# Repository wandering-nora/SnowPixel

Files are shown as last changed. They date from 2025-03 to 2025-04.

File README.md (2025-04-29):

# SnowPixel
Yet another 8x8 neopixel matrix... But hear me out, this one is a little special ❄️ 

This is a small 20x20x1.3mm module that can be seamlessly tiled without any wiring by soldering them together with the castellated holes.  
The built in solder jumpers in the data pads let the user decide whether the module sends and receives the data straight accross or at a 90 degree angle making any configuration possible.

The modules are meant to be used standalone or as an smd component in and of itself.  
The leds used are XL-1010RGBC-WS2812B 1x1mm leds which are the smallest currently available.  
If you have a clean 5V supply the capacitors on the back are usually not needed.  
This project is meant mainly as a test to push the pcb fab's specs to the limit and try a couple 3D printing ideas to obtain a thin, seamless display.



## 3D print
The 3D printed case is what brings the SnowPixel to life giving it proper square pixels. There's a standalone version for generic use and an smd version for when the pcb is soldered directly on a bigger pcb.  

The STL folder contains a bunch of common configurations, but the models are fully modular and can be easily edited with the OpenSCAD files.  

I'm currently experimenting with two methods for diffusing the light.  

### PET
These models are meant to be printed with PET (not PETG) on a PET diffusion film substrate.
This can be done by modifying a little the G-code to add an offset equal to the thickness of the film.

### PLA
These models are much simpler to print, they can be printed with normal pla (or any other plastic really) and only need the first layer to be printed in white and the rest in black.

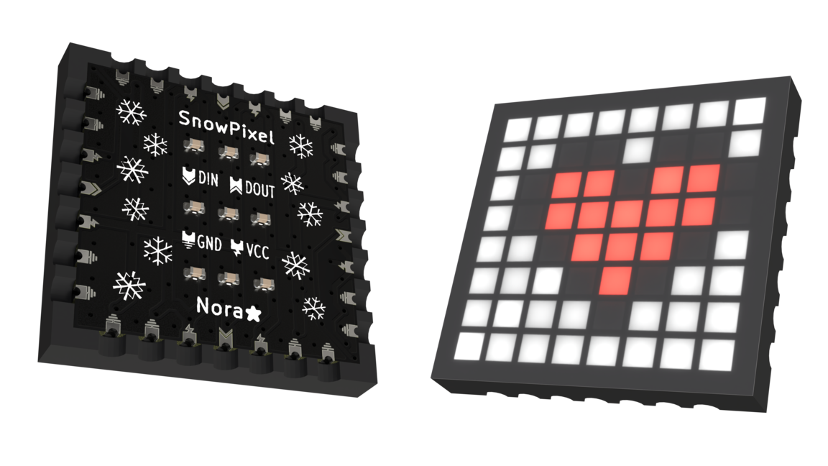
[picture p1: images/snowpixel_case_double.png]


 > Not an amazing render, I will update it with proper photos soon

## Manufacturing update
Even if quite out of spec for JLCPCB's cheapest offering (not paying for castellated holes and definitely going over spec for both the copper and silkscreen layers) the boards all turned out mostly fine!  
They definitely needed some cleanup as the edges were filled with burs from the castellated holes and the LED silkscreen wasn't printed all the way around.  
The boards are otherwise perfectly functional and pretty simple to assemble by hand with an hotplate.

#### Todo for v1.2
- [ ] Modify data jumpers for easier operation. (Maybe cuttable traces?)
- [ ] Make leds silkscreen thicker.

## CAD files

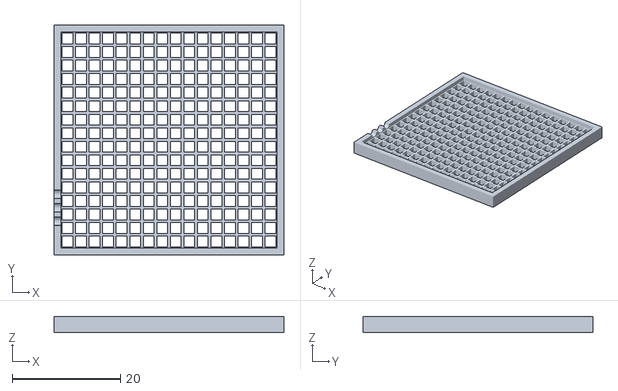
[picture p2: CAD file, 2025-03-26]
case/STL/PET/snowpixel_pet_16x16.stl
42.5 x 42.5 x 3.00

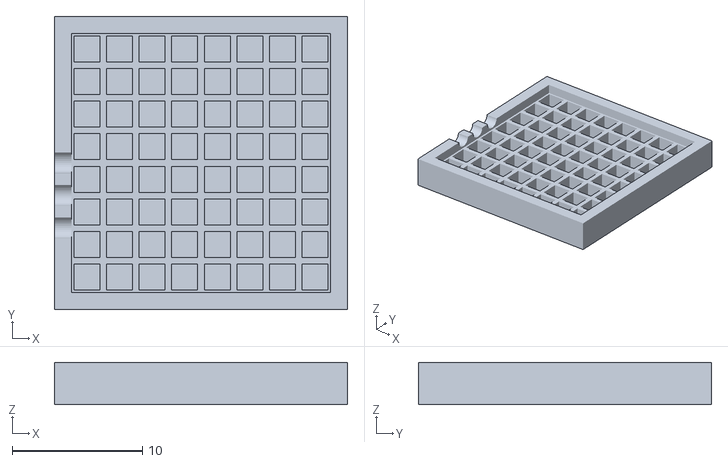
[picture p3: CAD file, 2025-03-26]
case/STL/PLA/snowpixel_pla_8x8.stl
22.5 x 22.5 x 3.25

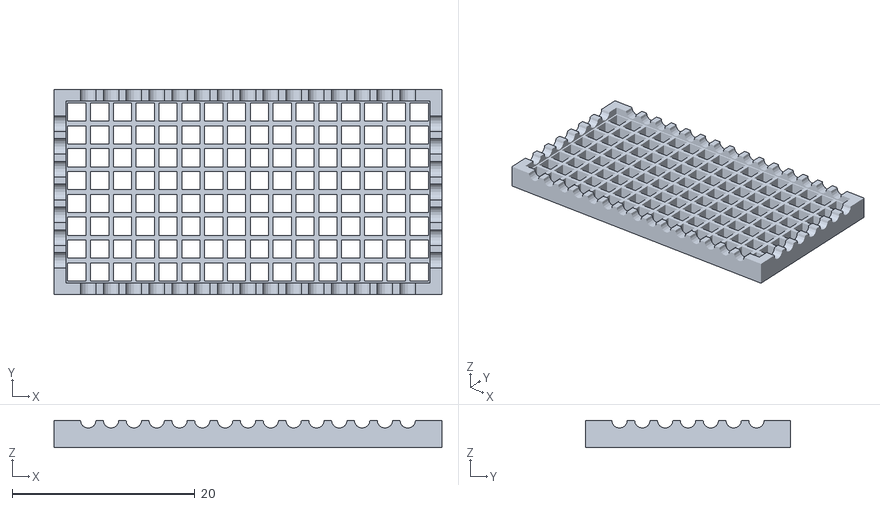
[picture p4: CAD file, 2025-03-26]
case/STL/PET/snowpixel_smd_pet_8x16.stl
42.5 x 22.5 x 3.00

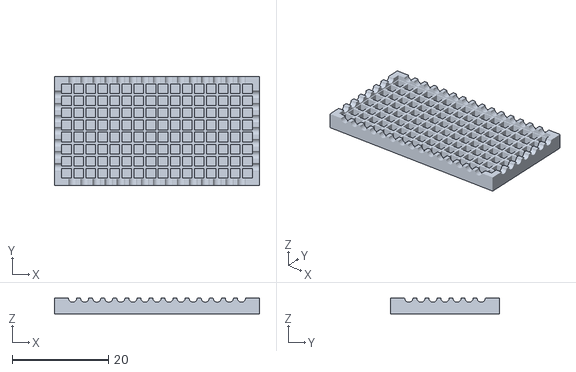
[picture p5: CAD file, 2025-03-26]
case/STL/PLA/snowpixel_smd_pla_8x16.stl
42.5 x 22.5 x 3.25

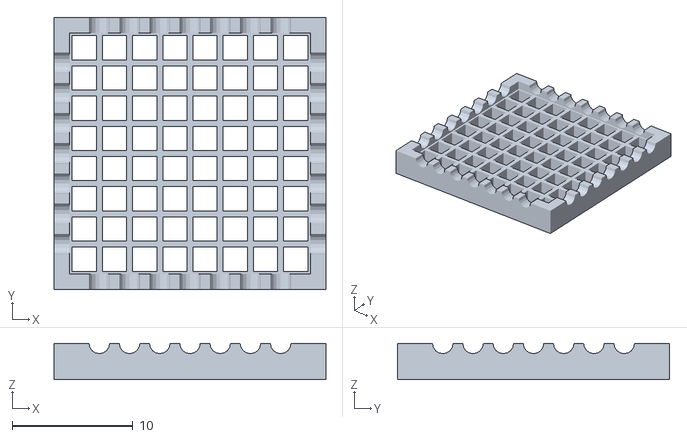
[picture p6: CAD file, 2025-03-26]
case/STL/PET/snowpixel_smd_pet_8x8.stl
22.5 x 22.5 x 3.00

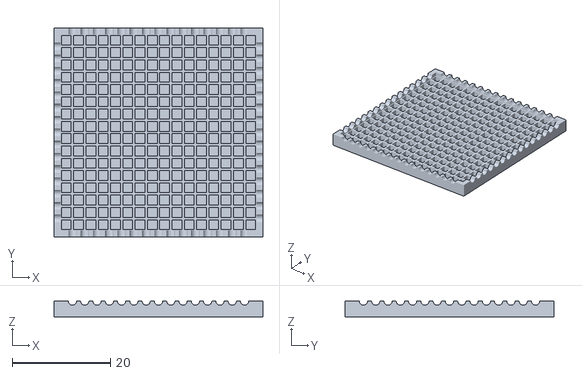
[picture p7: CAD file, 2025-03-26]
case/STL/PLA/snowpixel_smd_pla_16x16.stl
42.5 x 42.5 x 3.25

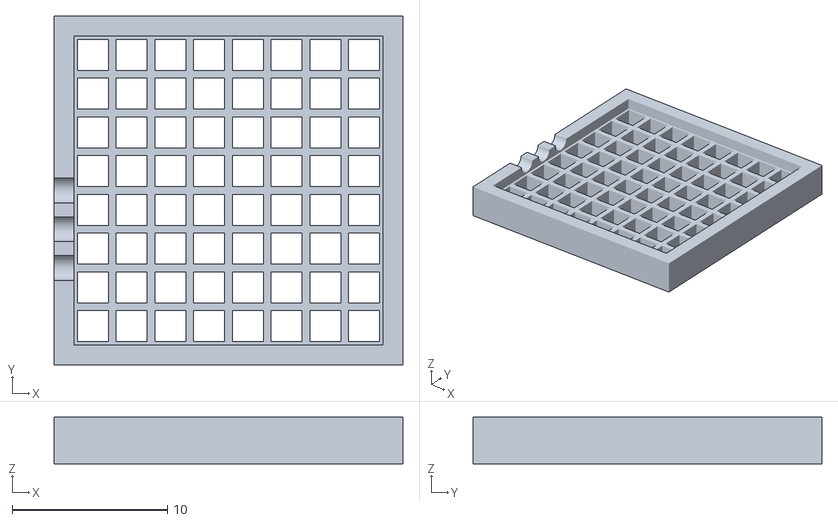
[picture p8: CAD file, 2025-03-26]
case/STL/PET/snowpixel_pet_8x8.stl
22.5 x 22.5 x 3.00

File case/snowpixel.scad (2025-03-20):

grid_size_x = 16; // number of pixels on x
grid_size_y = 16; // number of pixels on y

cell_size = 2.5; // pitch between pixels
inner_wall_thickness = 0.5; // I think you get this one
outer_wall_thickness = 1.5; // this one too
inner_wall_height = 2; // minimum TBD by experimentation
outer_wall_height = inner_wall_height + 1;
pcb_tolerance = 0.2; //wiggle room for pcb

hole_size = 0.5; // size for cable holes  

module grid() { // make readable code they said... 
    translate([0, 0, 0])
            cube([grid_size_y * cell_size - inner_wall_thickness + 2 * outer_wall_thickness, outer_wall_thickness, inner_wall_height]);
    translate([0, 0, inner_wall_height])
            cube([grid_size_y * cell_size - inner_wall_thickness + 2 * outer_wall_thickness, outer_wall_thickness - pcb_tolerance, outer_wall_height - inner_wall_height]);
    
    for (y = [1 : 1 : grid_size_x -1]) {
        translate([outer_wall_thickness, y * cell_size + outer_wall_thickness - inner_wall_thickness, 0])
            cube([grid_size_y * cell_size - inner_wall_thickness, inner_wall_thickness, inner_wall_height]);
    }
    
    translate([0, grid_size_x * cell_size + outer_wall_thickness - inner_wall_thickness, 0])
            cube([grid_size_y * cell_size - inner_wall_thickness + 2 * outer_wall_thickness, outer_wall_thickness, inner_wall_height]);
    translate([0, grid_size_x * cell_size + outer_wall_thickness - inner_wall_thickness + pcb_tolerance, inner_wall_height])
           cube([grid_size_y * cell_size - inner_wall_thickness + 2 * outer_wall_thickness, outer_wall_thickness - pcb_tolerance, outer_wall_height - inner_wall_height]);
    
    
    translate([0, 0, 0])
            cube([outer_wall_thickness, grid_size_x * cell_size - inner_wall_thickness + 2 * outer_wall_thickness, inner_wall_height]); 
    translate([0, 0, inner_wall_height])
            cube([outer_wall_thickness - pcb_tolerance, grid_size_x * cell_size - inner_wall_thickness + 2 * outer_wall_thickness, outer_wall_height - inner_wall_height]);
    
    for (x = [1 : 1 : grid_size_y - 1]) {
        translate([x * cell_size + outer_wall_thickness -inner_wall_thickness, outer_wall_thickness, 0])
            cube([inner_wall_thickness, grid_size_x * cell_size - inner_wall_thickness, inner_wall_height]);
    }
    
    translate([grid_size_y * cell_size + outer_wall_thickness - inner_wall_thickness, 0, 0])
            cube([outer_wall_thickness, grid_size_x * cell_size - inner_wall_thickness + 2 * outer_wall_thickness, inner_wall_height]);
    translate([grid_size_y * cell_size + outer_wall_thickness - inner_wall_thickness + pcb_tolerance, 0, inner_wall_height])
            cube([outer_wall_thickness - pcb_tolerance, grid_size_x * cell_size - inner_wall_thickness + 2 * outer_wall_thickness, outer_wall_height - inner_wall_height]);
}


color([0.9,0.8,1]) difference() { // make hole for cables 
    grid();
    translate([-0.1, cell_size * 2 - inner_wall_thickness/2 + outer_wall_thickness, outer_wall_height])
    rotate([0,90,0])
    cylinder(r=hole_size, h=outer_wall_height + 1, $fn=100);
    translate([-0.1, cell_size * 3 - inner_wall_thickness/2 + outer_wall_thickness, outer_wall_height])
    rotate([0,90,0])
    cylinder(r=hole_size, h=outer_wall_height + 1, $fn=100);
    translate([-0.1, cell_size * 4 - inner_wall_thickness/2 + outer_wall_thickness, outer_wall_height])
    rotate([0,90,0])
    cylinder(r=hole_size, h=outer_wall_height + 1, $fn=100);
    }

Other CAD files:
case/STL/PLA/snowpixel_pla_8x16.stl
case/STL/PET/snowpixel_pet_8x16.stl
case/STL/PLA/snowpixel_smd_pla_8x8.stl
case/STL/PET/snowpixel_smd_pet_16x16.stl
case/STL/PLA/snowpixel_pla_16x16.stl
case/snowpixel_pet.scad
case/snowpixel_pla.scad
case/snowpixel_smd.scad
case/OpenSCAD/snowpixel_pet.scad
case/OpenSCAD/snowpixel_pla.scad
case/OpenSCAD/snowpixel_smd_pet.scad
case/OpenSCAD/snowpixel_smd_pla.scad
case/snowpixel_smd_pla.scad

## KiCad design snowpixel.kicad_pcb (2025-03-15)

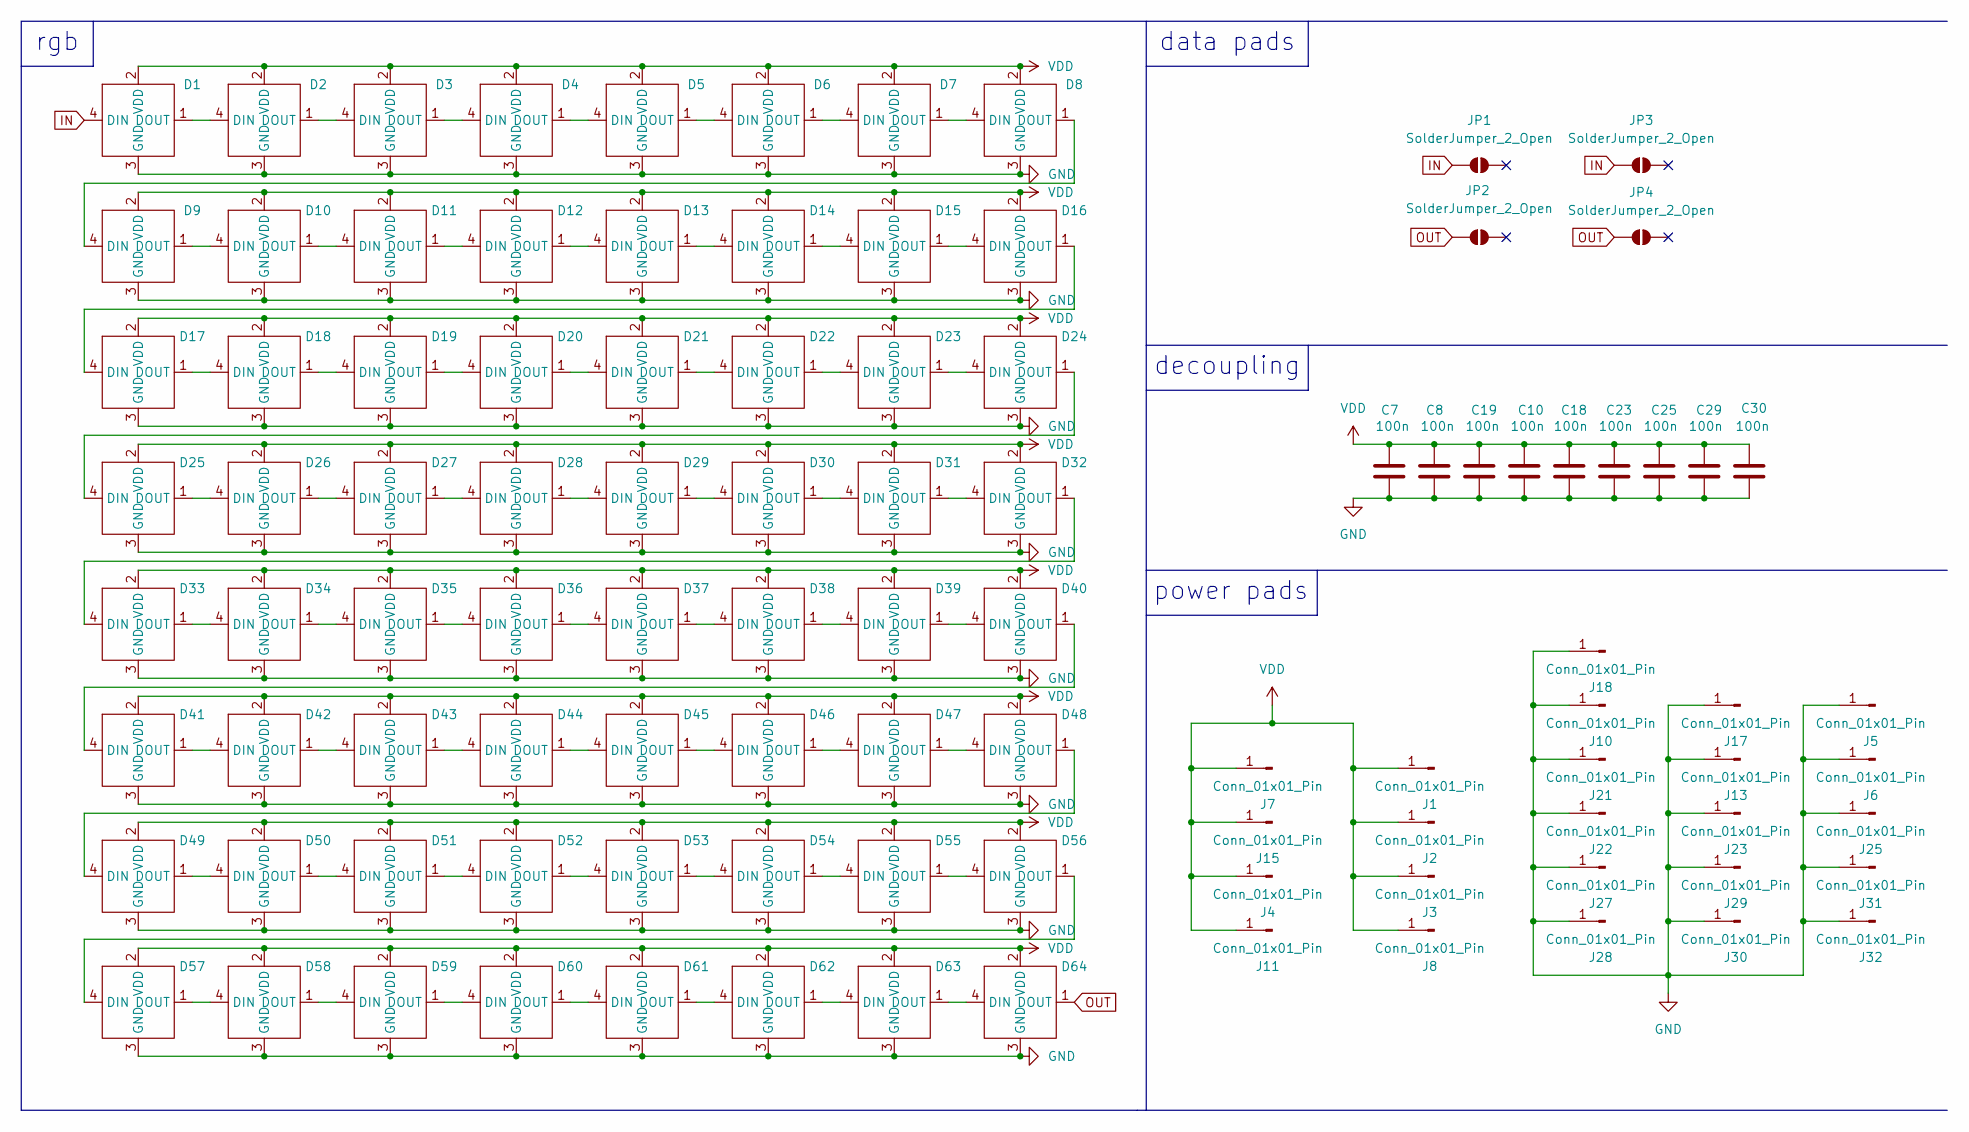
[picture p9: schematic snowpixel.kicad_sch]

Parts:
C7, C8, C10, C18, C19, C23, C25, C29, C30: 100n; C_0402_1005Metric
D1, D2, D3, D4, D5, D6, D7, D8, D9, D10, D11, D12, D13, D14, D15, D16, D17, D18, D19, D20, D21, D22, D23, D24, D25, D26, D27, D28, D29, D30, D31, D32, D33, D34, D35, D36, D37, D38, D39, D40, D41, D42, D43, D44, D45, D46, D47, D48, D49, D50, D51, D52, D53, D54, D55, D56, D57, D58, D59, D60, D61, D62, D63, D64: XL-1010RGBC-WS28128B
J1, J2, J3, J4, J7, J8, J11, J15: Conn_01x01_Pin; matrix-pad-vcc
J5, J6, J10, J13, J17, J18, J21, J22, J23, J25, J27, J28, J29, J30, J31, J32: Conn_01x01_Pin; matrix-pad-gn
JP1, JP3: SolderJumper_2_Open; matrix-pad-din
JP2, JP4: SolderJumper_2_Open; matrix-pad-dout

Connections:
GND: C7.2, C8.2, C10.2, C18.2, C19.2, C23.2, C25.2, C29.2, C30.2, D1.3 (GND), D2.3 (GND), D3.3 (GND), D4.3 (GND), D5.3 (GND), D6.3 (GND), D7.3 (GND), D8.3 (GND), D9.3 (GND), D10.3 (GND), D11.3 (GND), D12.3 (GND), D13.3 (GND), D14.3 (GND), D15.3 (GND), D16.3 (GND), D17.3 (GND), D18.3 (GND), D19.3 (GND), D20.3 (GND), D21.3 (GND), D22.3 (GND), D23.3 (GND), D24.3 (GND), D25.3 (GND), D26.3 (GND), D27.3 (GND), D28.3 (GND), D29.3 (GND), D30.3 (GND), D31.3 (GND), D32.3 (GND), D33.3 (GND), D34.3 (GND), D35.3 (GND), D36.3 (GND), D37.3 (GND), D38.3 (GND), D39.3 (GND), D40.3 (GND), D41.3 (GND), D42.3 (GND), D43.3 (GND), D44.3 (GND), D45.3 (GND), D46.3 (GND), D47.3 (GND), D48.3 (GND), D49.3 (GND), D50.3 (GND), D51.3 (GND), D52.3 (GND), D53.3 (GND), D54.3 (GND), D55.3 (GND), D56.3 (GND), D57.3 (GND), D58.3 (GND), D59.3 (GND), D60.3 (GND), D61.3 (GND), D62.3 (GND), D63.3 (GND), D64.3 (GND), J5.1, J6.1, J10.1, J13.1, J17.1, J18.1, J21.1, J22.1, J23.1, J25.1, J27.1, J28.1, J29.1, J30.1, J31.1, J32.1
IN: D1.4 (DIN), JP1.2 (B), JP3.2 (B)
unnamed: D1.1 (DOUT), D2.4 (DIN)
unnamed: D2.1 (DOUT), D3.4 (DIN)
unnamed: D3.1 (DOUT), D4.4 (DIN)
unnamed: D4.1 (DOUT), D5.4 (DIN)
unnamed: D5.1 (DOUT), D6.4 (DIN)
unnamed: D6.1 (DOUT), D7.4 (DIN)
unnamed: D7.1 (DOUT), D8.4 (DIN)
unnamed: D8.1 (DOUT), D9.4 (DIN)
unnamed: D9.1 (DOUT), D10.4 (DIN)
unnamed: D10.1 (DOUT), D11.4 (DIN)
unnamed: D11.1 (DOUT), D12.4 (DIN)
unnamed: D12.1 (DOUT), D13.4 (DIN)
unnamed: D13.1 (DOUT), D14.4 (DIN)
unnamed: D14.1 (DOUT), D15.4 (DIN)
unnamed: D15.1 (DOUT), D16.4 (DIN)
unnamed: D16.1 (DOUT), D17.4 (DIN)
unnamed: D17.1 (DOUT), D18.4 (DIN)
unnamed: D18.1 (DOUT), D19.4 (DIN)
unnamed: D19.1 (DOUT), D20.4 (DIN)
unnamed: D20.1 (DOUT), D21.4 (DIN)
unnamed: D21.1 (DOUT), D22.4 (DIN)
unnamed: D22.1 (DOUT), D23.4 (DIN)
unnamed: D23.1 (DOUT), D24.4 (DIN)
unnamed: D24.1 (DOUT), D25.4 (DIN)
unnamed: D25.1 (DOUT), D26.4 (DIN)
unnamed: D26.1 (DOUT), D27.4 (DIN)
unnamed: D27.1 (DOUT), D28.4 (DIN)
unnamed: D28.1 (DOUT), D29.4 (DIN)
unnamed: D29.1 (DOUT), D30.4 (DIN)
unnamed: D30.1 (DOUT), D31.4 (DIN)
unnamed: D31.1 (DOUT), D32.4 (DIN)
unnamed: D32.1 (DOUT), D33.4 (DIN)
unnamed: D33.1 (DOUT), D34.4 (DIN)
unnamed: D34.1 (DOUT), D35.4 (DIN)
unnamed: D35.1 (DOUT), D36.4 (DIN)
unnamed: D36.1 (DOUT), D37.4 (DIN)
unnamed: D37.1 (DOUT), D38.4 (DIN)
unnamed: D38.1 (DOUT), D39.4 (DIN)
unnamed: D39.1 (DOUT), D40.4 (DIN)
unnamed: D40.1 (DOUT), D41.4 (DIN)
unnamed: D41.1 (DOUT), D42.4 (DIN)
unnamed: D42.1 (DOUT), D43.4 (DIN)
unnamed: D43.1 (DOUT), D44.4 (DIN)
unnamed: D44.1 (DOUT), D45.4 (DIN)
unnamed: D45.1 (DOUT), D46.4 (DIN)
unnamed: D46.1 (DOUT), D47.4 (DIN)
unnamed: D47.1 (DOUT), D48.4 (DIN)
unnamed: D48.1 (DOUT), D49.4 (DIN)
unnamed: D49.1 (DOUT), D50.4 (DIN)
unnamed: D50.1 (DOUT), D51.4 (DIN)
unnamed: D51.1 (DOUT), D52.4 (DIN)
unnamed: D52.1 (DOUT), D53.4 (DIN)
unnamed: D53.1 (DOUT), D54.4 (DIN)
unnamed: D54.1 (DOUT), D55.4 (DIN)
unnamed: D55.1 (DOUT), D56.4 (DIN)
unnamed: D56.1 (DOUT), D57.4 (DIN)
unnamed: D57.1 (DOUT), D58.4 (DIN)
unnamed: D58.1 (DOUT), D59.4 (DIN)
unnamed: D59.1 (DOUT), D60.4 (DIN)
unnamed: D60.1 (DOUT), D61.4 (DIN)
unnamed: D61.1 (DOUT), D62.4 (DIN)
unnamed: D62.1 (DOUT), D63.4 (DIN)
unnamed: D63.1 (DOUT), D64.4 (DIN)
OUT: D64.1 (DOUT), JP2.2 (B), JP4.2 (B)
VDD: C7.1, C8.1, C10.1, C18.1, C19.1, C23.1, C25.1, C29.1, C30.1, D1.2 (VDD), D2.2 (VDD), D3.2 (VDD), D4.2 (VDD), D5.2 (VDD), D6.2 (VDD), D7.2 (VDD), D8.2 (VDD), D9.2 (VDD), D10.2 (VDD), D11.2 (VDD), D12.2 (VDD), D13.2 (VDD), D14.2 (VDD), D15.2 (VDD), D16.2 (VDD), D17.2 (VDD), D18.2 (VDD), D19.2 (VDD), D20.2 (VDD), D21.2 (VDD), D22.2 (VDD), D23.2 (VDD), D24.2 (VDD), D25.2 (VDD), D26.2 (VDD), D27.2 (VDD), D28.2 (VDD), D29.2 (VDD), D30.2 (VDD), D31.2 (VDD), D32.2 (VDD), D33.2 (VDD), D34.2 (VDD), D35.2 (VDD), D36.2 (VDD), D37.2 (VDD), D38.2 (VDD), D39.2 (VDD), D40.2 (VDD), D41.2 (VDD), D42.2 (VDD), D43.2 (VDD), D44.2 (VDD), D45.2 (VDD), D46.2 (VDD), D47.2 (VDD), D48.2 (VDD), D49.2 (VDD), D50.2 (VDD), D51.2 (VDD), D52.2 (VDD), D53.2 (VDD), D54.2 (VDD), D55.2 (VDD), D56.2 (VDD), D57.2 (VDD), D58.2 (VDD), D59.2 (VDD), D60.2 (VDD), D61.2 (VDD), D62.2 (VDD), D63.2 (VDD), D64.2 (VDD), J1.1, J2.1, J3.1, J4.1, J7.1, J8.1, J11.1, J15.1

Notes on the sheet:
data pads
power pads
rgb
decoupling

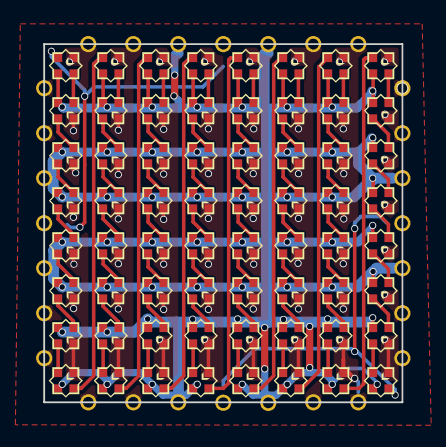
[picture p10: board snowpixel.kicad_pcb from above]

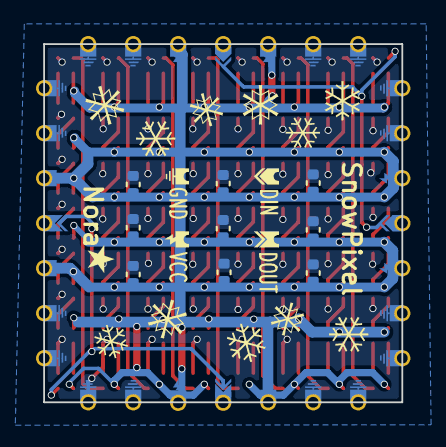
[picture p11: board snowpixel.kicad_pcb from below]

Board: 2 copper layers, 19.9 x 19.9 mm, 101 parts (37 on the bottom side), 67 nets.

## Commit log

2025-03-11 Initial commit with project files
    [snowpixel.kicad_pcb, snowpixel.kicad_sch]
2025-03-12 Change silkscreen text
    [snowpixel.kicad_pcb]
2025-03-15 Added v1 gerber files
    [snowpixel-B_Cu.gbl, snowpixel-B_Mask.gbs, snowpixel-B_Paste.gbp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]
2025-03-18 Change folder structure for release
    [snowpixel-B_Cu.gbl, snowpixel-B_Mask.gbs, snowpixel-B_Paste.gbp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]
2025-03-20 Add fully modular OpenSCAD model
    [snowpixel-8x16.stl, snowpixel.scad]
2025-03-20 Add 16x16 stl
    [snowpixel-16x16.stl, snowpixel.scad]
2025-03-23 Added 3d model for smd usage
    [snowpixel_smd.scad]
2025-03-26 Added pla 3d models
    [snowpixel_pla.scad, snowpixel_smd_pla.scad]
2025-03-26 Removed stl files
    [snowpixel-16x16.stl, snowpixel-8x16.stl]
2025-03-26 Renamed 3d models
    [snowpixel_pet.scad, snowpixel_smd_pet.scad]
2025-03-26 Add stl files and organize
    [snowpixel_pet.scad, snowpixel_pet_16x16.stl, snowpixel_pet_8x16.stl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]
2025-03-31 add 3d print images
